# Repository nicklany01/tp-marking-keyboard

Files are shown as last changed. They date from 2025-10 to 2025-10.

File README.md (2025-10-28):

# TP Marking Keyboard
## Releases
The built program can be found in github actions under the corresponding commit. There will be a file called "fireware.zip" that can be downloaded and flashed to the keyboard.
## Flashing Instructions
1. Connect the keyboard via a USB cable.
2. Double click the reset button on the keyboard (found below the rotary encoder) to enter bootloader mode. The keyboard should show up as a mass storage device on your computer.
3. Copy the "firmware.uf2" file from the downloaded release to the mass storage device to flash the keyboard. The storage device should automatically eject and the keyboard will reboot with the new firmware.
## Local Build Instructions
Source code is built in github actions using the ZMK firmware framework. To build the firmware locally, follow these steps:
1. Clone the ZMK repository using the following command:
```
git clone https://github.com/zmkfirmware/zmk.git
```
2. Set up the Zephyr SDK as described [here](https://docs.zephyrproject.org/3.5.0/develop/getting_started/index.html)
3. From the zmk directory, run the following commands to build the firwmare, ensuring to replace "/path/to/this/repo/config" with the path to the config directory in this repository:
```
cd app
west build -p -b nice_nano_v2 -- -DSHIELD=tp_marking_keyboard -DZMK_CONFIG=/path/to/this/repo/config
```
The built firmware file can be found at "/path/to/zmk/app/build/zephyr/zmk.uf2", and can be flashed with the [flash instructions](#flashing-instructions) above, treating "zmk.uf2" as "firmware.uf2".
For more information, see the [ZMK documentation](https://zmk.dev/docs/development/local-toolchain/setup/native) and [Zephyr documentation](https://docs.zephyrproject.org/3.5.0/develop/getting_started/index.html)

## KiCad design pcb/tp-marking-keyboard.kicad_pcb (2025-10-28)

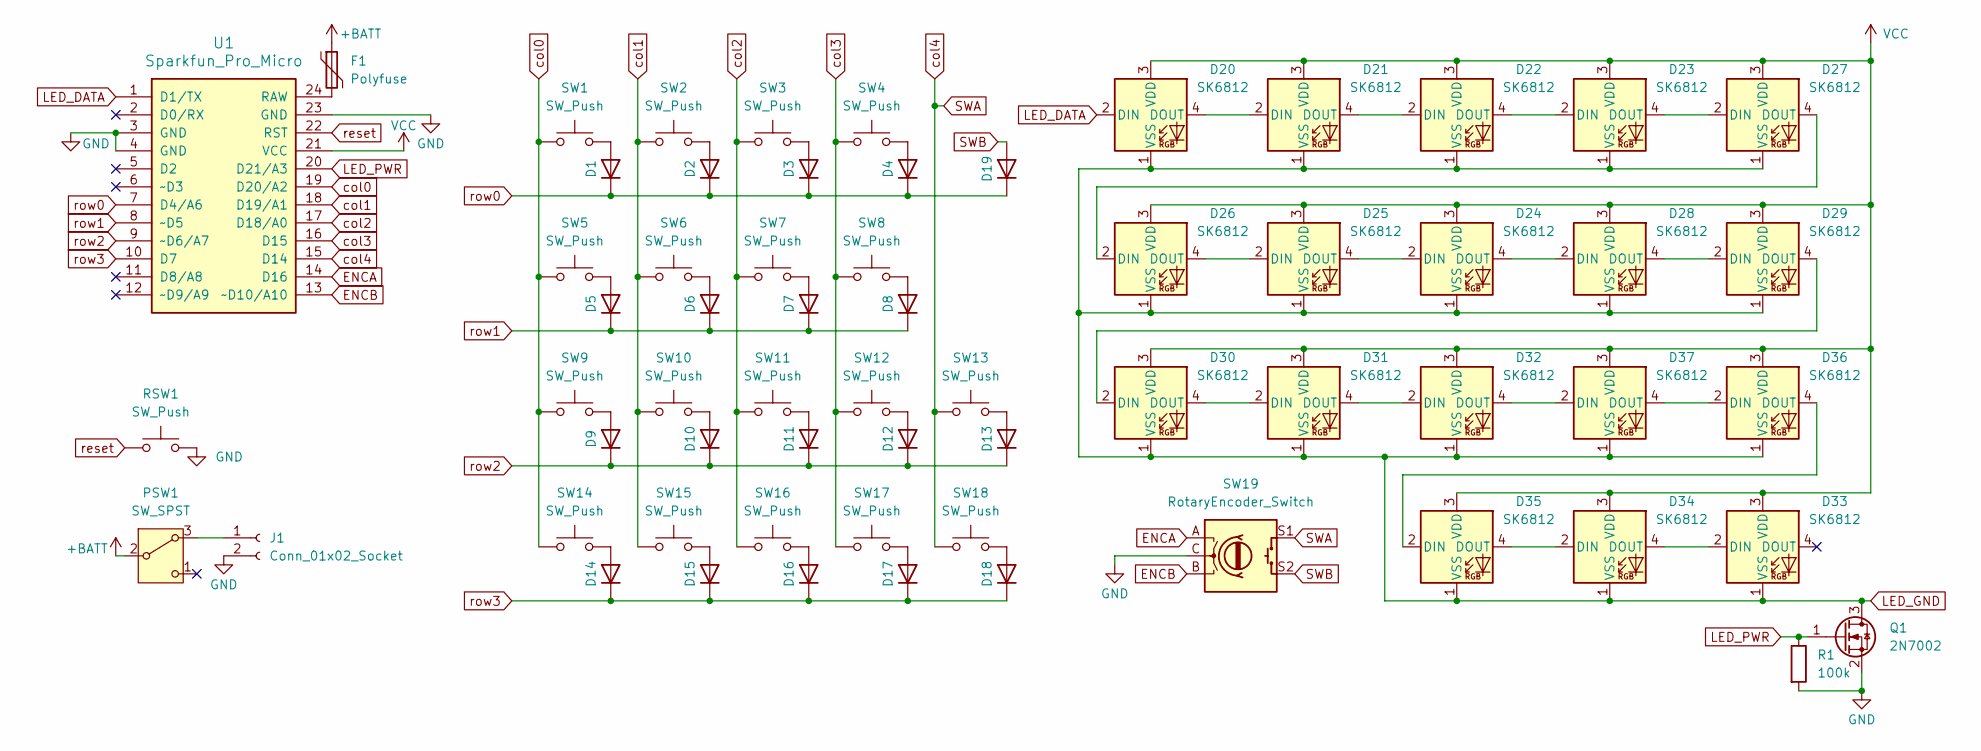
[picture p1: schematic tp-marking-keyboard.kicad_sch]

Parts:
D1, D2, D3, D4, D5, D6, D7, D8, D9, D10, D11, D12, D13, D14, D15, D16, D17, D18, D19: 1N4148WT; D_SOD-523
D20, D21, D22, D23, D24, D25, D26, D27, D28, D29, D30, D31, D32, D33, D34, D35, D36, D37: SK6812; SK6812_4020_SIDE_rev2
F1: Polyfuse; 0805_2012_nonpolarised
J1: Conn_01x02_Socket; JST_PH_S2B-PH-SM4-TB_1x02-1MP_P2.00mm_Horizontal
PSW1: SW_SPST; SW_SPDT_PCM12
Q1: 2N7002; SOT-23-3
R1: 100k; 0805_2012_nonpolarised
RSW1: SW_Push; SW_SPST_FSMSM
SW1, SW2, SW3, SW4, SW5, SW6, SW7, SW8, SW9, SW10, SW11, SW12, SW13, SW14, SW15, SW16, SW17, SW18: SW_Push; gateron-ks27-hotswap-reversible
SW19: RotaryEncoder_Switch; RotaryEncoder_Alps_EC11E-Switch_Vertical_H20mm
U1: Sparkfun_Pro_Micro

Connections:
+BATT: F1.1, PSW1.2 (B)
CS: U1.2 (D0/RX)
ENCA: SW19.A, U1.14 (D16)
ENCB: SW19.B, U1.13 (~D10/A10)
GND: J1.2, Q1.2 (S), R1.2, RSW1.2, SW19.C, U1.3 (GND), U1.4 (GND), U1.23 (GND)
LED_DATA: D20.2 (DIN), U1.1 (D1/TX)
LED_GND: D20.1 (VSS), D21.1 (VSS), D22.1 (VSS), D23.1 (VSS), D24.1 (VSS), D25.1 (VSS), D26.1 (VSS), D27.1 (VSS), D28.1 (VSS), D29.1 (VSS), D30.1 (VSS), D31.1 (VSS), D32.1 (VSS), D33.1 (VSS), D34.1 (VSS), D35.1 (VSS), D36.1 (VSS), D37.1 (VSS), Q1.3 (D)
LED_PWR: Q1.1 (G), R1.1, U1.20 (D21/A3)
unnamed: D1.2 (A), SW1.2
unnamed: D2.2 (A), SW2.2
unnamed: D3.2 (A), SW3.2
unnamed: D4.2 (A), SW4.2
unnamed: D5.2 (A), SW5.2
unnamed: D6.2 (A), SW6.2
unnamed: D7.2 (A), SW7.2
unnamed: D8.2 (A), SW8.2
unnamed: D9.2 (A), SW9.2
unnamed: D10.2 (A), SW10.2
unnamed: D11.2 (A), SW11.2
unnamed: D12.2 (A), SW12.2
unnamed: D13.2 (A), SW13.2
unnamed: D14.2 (A), SW14.2
unnamed: D15.2 (A), SW15.2
unnamed: D16.2 (A), SW16.2
unnamed: D17.2 (A), SW17.2
unnamed: D18.2 (A), SW18.2
unnamed: D20.4 (DOUT), D21.2 (DIN)
unnamed: D21.4 (DOUT), D22.2 (DIN)
unnamed: D22.4 (DOUT), D23.2 (DIN)
unnamed: D23.4 (DOUT), D27.2 (DIN)
unnamed: D24.2 (DIN), D25.4 (DOUT)
unnamed: D24.4 (DOUT), D28.2 (DIN)
unnamed: D25.2 (DIN), D26.4 (DOUT)
unnamed: D26.2 (DIN), D27.4 (DOUT)
unnamed: D28.4 (DOUT), D29.2 (DIN)
unnamed: D29.4 (DOUT), D30.2 (DIN)
unnamed: D30.4 (DOUT), D31.2 (DIN)
unnamed: D31.4 (DOUT), D32.2 (DIN)
unnamed: D32.4 (DOUT), D37.2 (DIN)
unnamed: D33.2 (DIN), D34.4 (DOUT)
unnamed: D34.2 (DIN), D35.4 (DOUT)
unnamed: D35.2 (DIN), D36.4 (DOUT)
unnamed: D36.2 (DIN), D37.4 (DOUT)
unnamed: J1.1, PSW1.3 (A)
unnamed: F1.2, U1.24 (RAW)
SWA: SW13.1, SW18.1, SW19.S1, U1.15 (D14)
SWB: D19.2 (A), SW19.S2
VCC: D20.3 (VDD), D21.3 (VDD), D22.3 (VDD), D23.3 (VDD), D24.3 (VDD), D25.3 (VDD), D26.3 (VDD), D27.3 (VDD), D28.3 (VDD), D29.3 (VDD), D30.3 (VDD), D31.3 (VDD), D32.3 (VDD), D33.3 (VDD), D34.3 (VDD), D35.3 (VDD), D36.3 (VDD), D37.3 (VDD), U1.21 (VCC)
col0: SW1.1, SW5.1, SW9.1, SW14.1, U1.19 (D20/A2)
col1: SW2.1, SW6.1, SW10.1, SW15.1, U1.18 (D19/A1)
col2: SW3.1, SW7.1, SW11.1, SW16.1, U1.17 (D18/A0)
col3: SW4.1, SW8.1, SW12.1, SW17.1, U1.16 (D15)
reset: RSW1.1, U1.22 (RST)
row0: D1.1 (K), D2.1 (K), D3.1 (K), D4.1 (K), D19.1 (K), U1.7 (D4/A6)
row1: D5.1 (K), D6.1 (K), D7.1 (K), D8.1 (K), U1.8 (~D5)
row2: D9.1 (K), D10.1 (K), D11.1 (K), D12.1 (K), D13.1 (K), U1.9 (~D6/A7)
row3: D14.1 (K), D15.1 (K), D16.1 (K), D17.1 (K), D18.1 (K), U1.10 (D7)

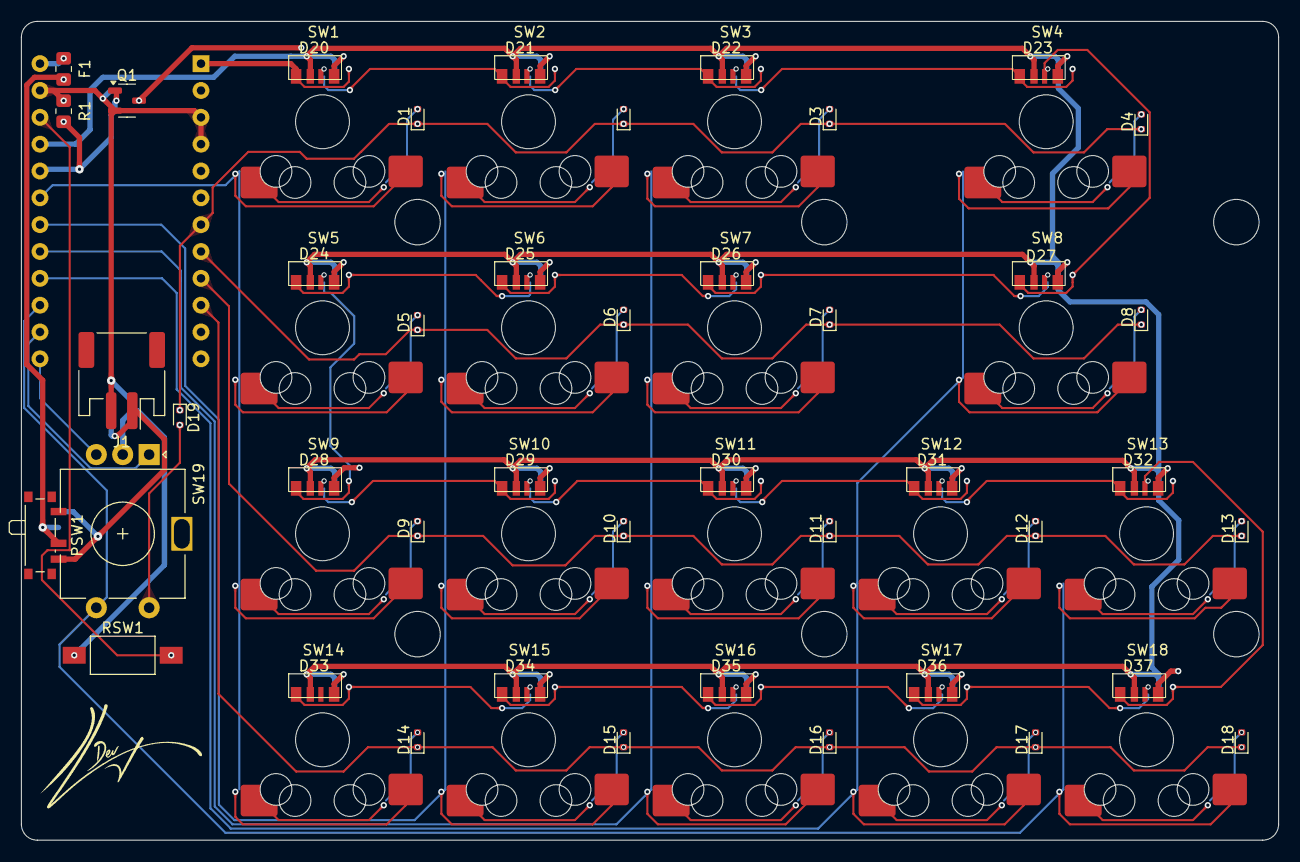
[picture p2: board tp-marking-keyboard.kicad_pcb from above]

Board: 2 copper layers, 119.0 x 77.5 mm, 63 parts (1 on the bottom side), 56 nets.

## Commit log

2025-10-28 Add PCB design
    [tp-marking-keyboard.kicad_pcb, tp-marking-keyboard.kicad_sch]
2025-10-28 Move led footprints lower
    [tp-marking-keyboard.kicad_pcb]
2025-10-28 Add board overlay
2025-10-28 Add led underglow foundations
2025-10-30 Add rotary encoder
2025-10-30 Ajust rotary encoder rotation increments
